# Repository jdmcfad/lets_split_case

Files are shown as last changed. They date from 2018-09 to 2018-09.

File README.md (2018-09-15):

The Brutalist case

These .dxf files were made with LibreCAD 2.2.0-rc1.  Here were my steps to build a concrete Let's Split case (the steps build a case for one half):

1. Buy a pre-primed dimensioned 1x6 (0.75"x5.5").
2. Cut out the parts in `cuts.dxf`, plus two 12" sections.
3. Assemble the parts into a mold according to `assembly.dxf`.  I used star-drive 1 1/4" screws to sandwich the parts between the 12" sections.  I used the measurements to the x axis to pre-drill the screw holes.
4. Spray a couple more coats of gloss primer into the assembled molds.  I'm not sure if this is necessary, but I did it.
5. Print the template in `template.dxf` at 1:1 scale.  Compare the printed template to your Let's Split PCB and plate holes to ensure it is to scale.  Use it to place your standoffs -- I used silicone rubber plugs in the molds which, when molded, made wells that I epoxied standoffs into.
6. Use silicone bathtub caulk to fill/round out all of the edges inside the mold.  I used my finger to apply it, plus denatured alcohol for cleanup. 
7. Pour concrete and finish according to typical concrete countertop instructions.  I used Tuff Duck brand countertop sealant from Amazon, applied according to the manufacturer's directions.

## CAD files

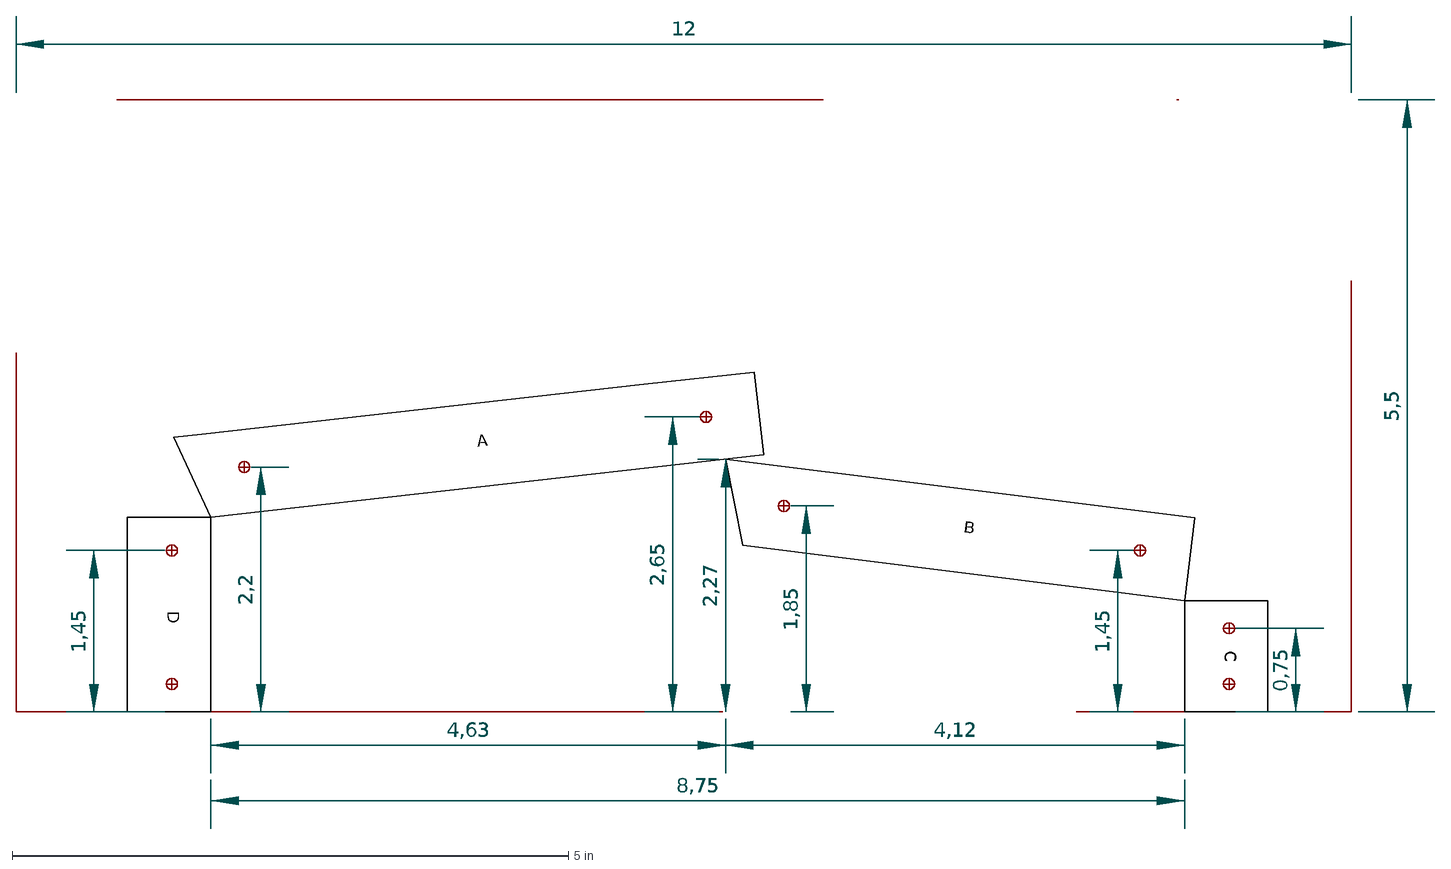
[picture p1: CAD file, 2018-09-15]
assembly.dxf
C
D
B
A
2,27
4,63
4,12
8,75
12
5,5
1,45
2,2
2,65
1,85
0,75

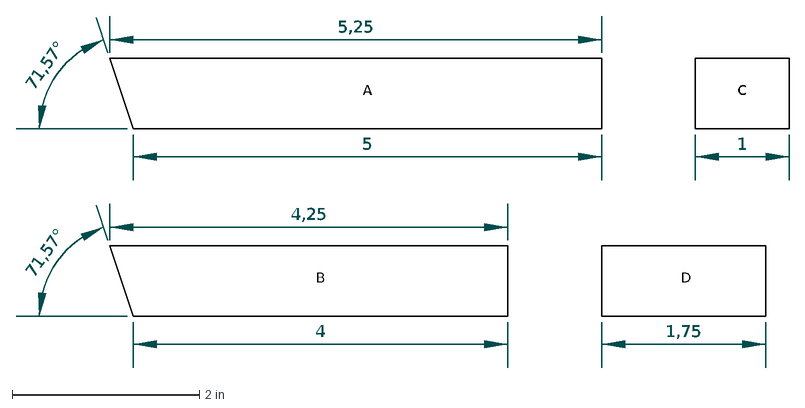
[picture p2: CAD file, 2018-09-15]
cuts.dxf
4
4,25
5,25
5
1
B
A
C
71,57°
D
1,75

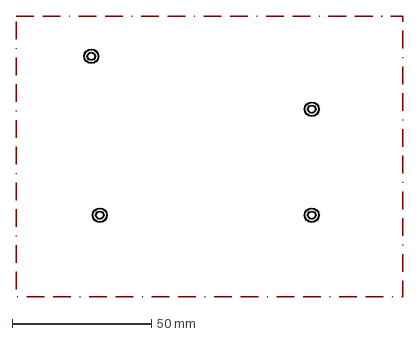
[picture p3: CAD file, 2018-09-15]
template.dxf
139.0 x 101.0 mm
